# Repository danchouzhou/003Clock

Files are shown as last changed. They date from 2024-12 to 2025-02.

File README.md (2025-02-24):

# 003Clock
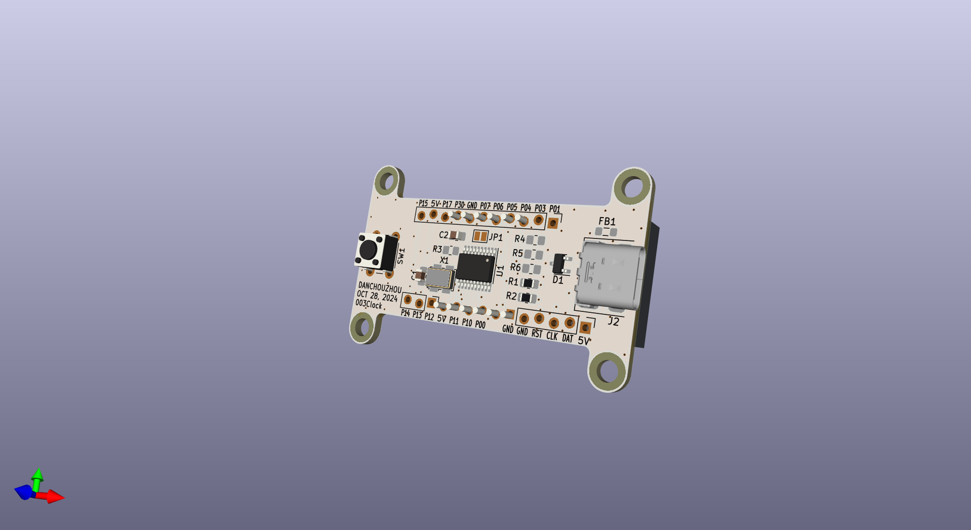
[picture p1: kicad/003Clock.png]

## Usage
### To clone this project
This project work with submodule from Nuvoton corporation. You need to initialize submodules by passing ``--recurse-submodules`` to the ``git clone`` command.
```
git clone https://github.com/danchouzhou/003Clock.git --recurse-submodules
```

### Build tools
Please make sure the installation path is the same as the one in `setting.json`.
- [SDCC 4.2.0](https://sourceforge.net/projects/sdcc/files/sdcc-win64/4.2.0/)
- [Nu-Link_Command_Tool_V3.17.7691r](https://www.nuvoton.com/tool-and-software/software-tool/programmer-tool/)

### Build the firmware
```
cd firmware/003Clock
```
Simply ``./build.bat``. ``main.bin`` should be inside the ``Objects`` folder.
```
./build.bat
```
### Flash the firmware by Nu-Link programmer (ICP)
```
./flash.bat
```
### Flash the firmware without a Nu-Link programmer (ISP)
1. Download the [NuMicro ISP Programming Tool](https://www.nuvoton.com/tool-and-software/software-tool/programmer-tool/)
2. Connect USB-UART adapter to PC
3. Select the COM port and then press `connect`\
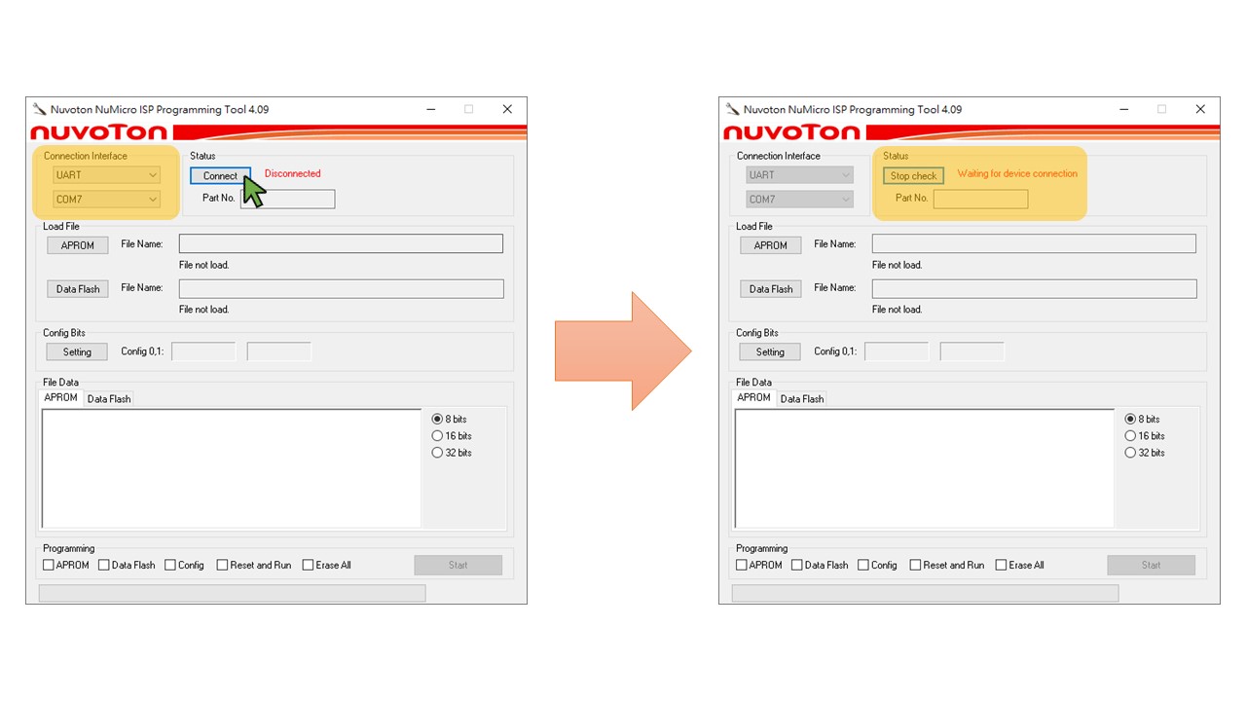
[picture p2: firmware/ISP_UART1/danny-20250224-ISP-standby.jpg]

4. Connect the target device to the USB-UART adapter, ISP Tool should show `connected`\
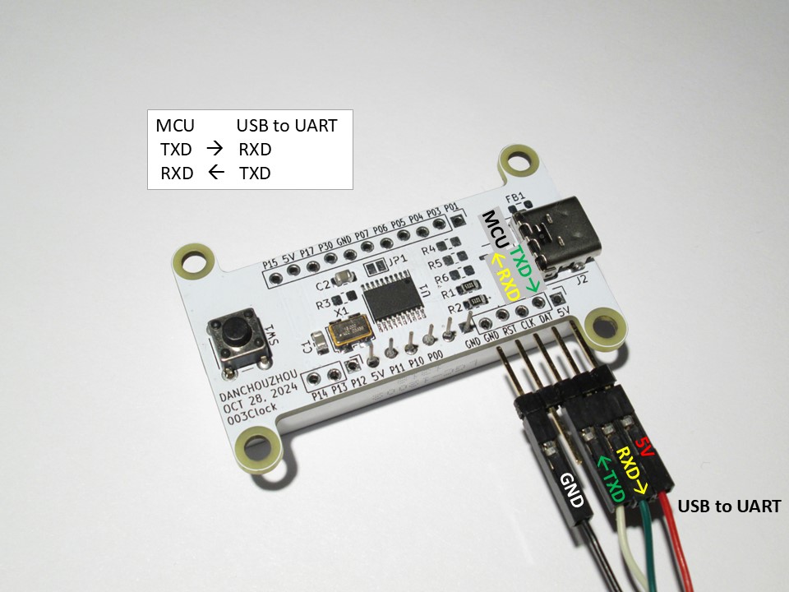
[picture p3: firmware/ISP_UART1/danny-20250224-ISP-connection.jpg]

5. Select APROM file and check `APROM` and `Reset and Run`, then press `Start`\
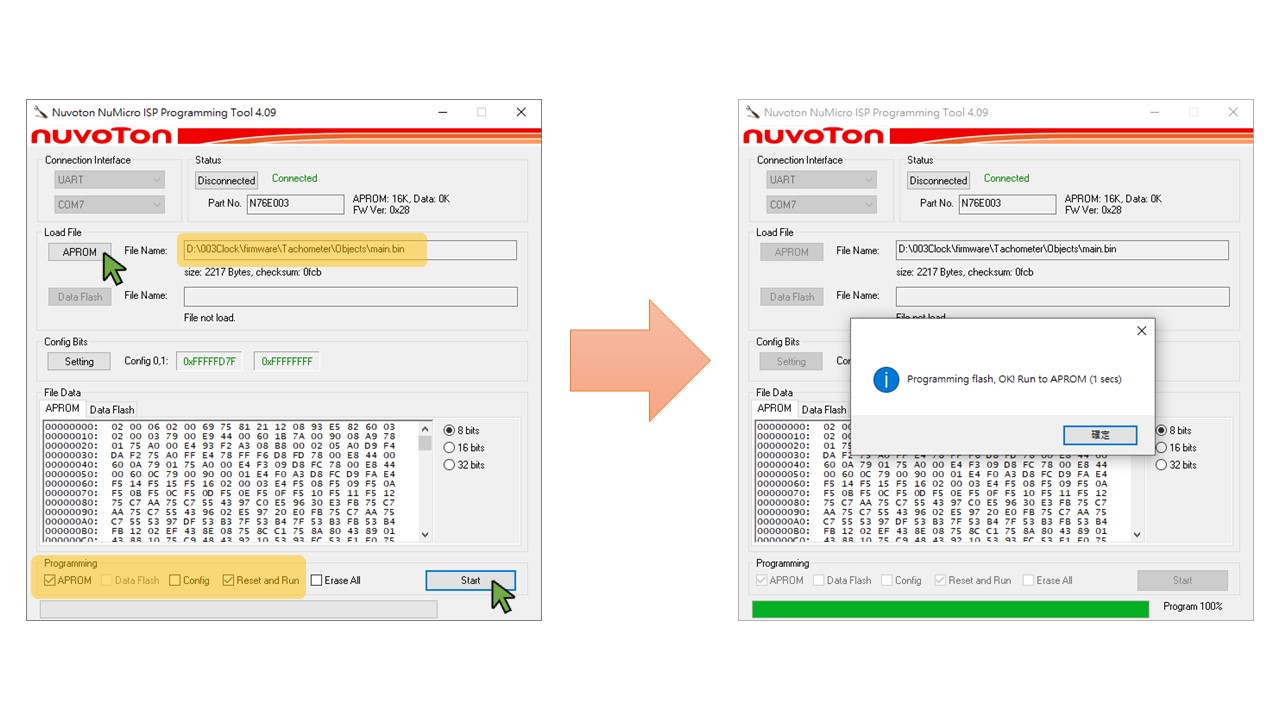
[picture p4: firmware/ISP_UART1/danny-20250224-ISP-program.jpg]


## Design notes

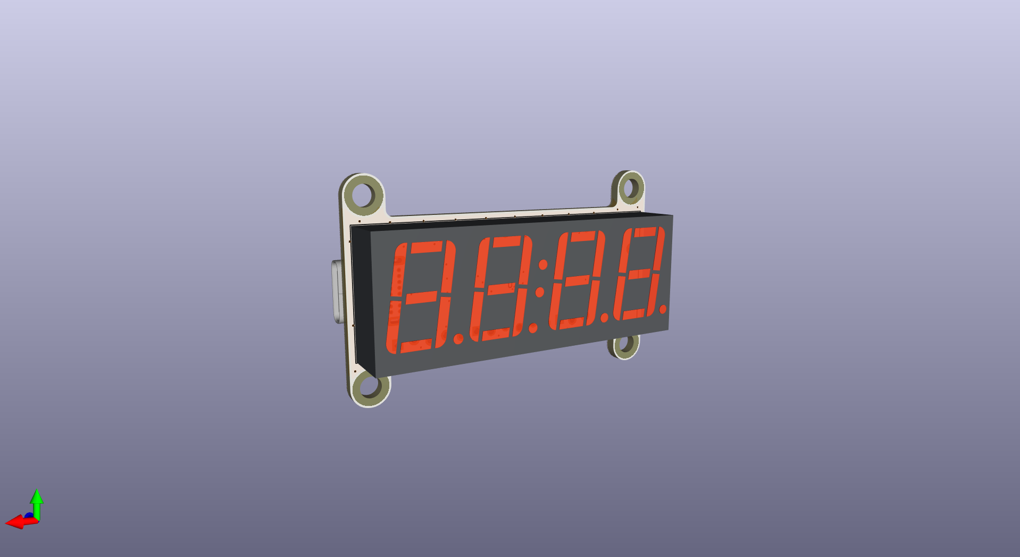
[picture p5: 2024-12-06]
kicad/003Clock_back.png

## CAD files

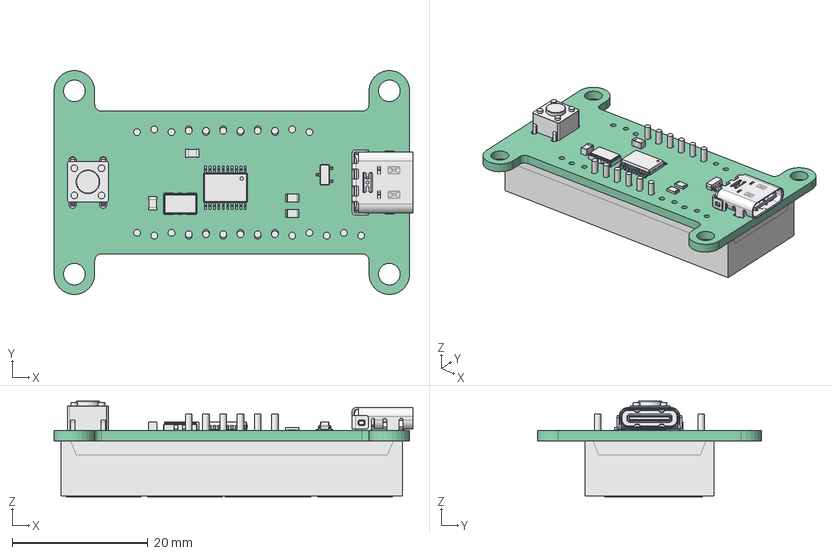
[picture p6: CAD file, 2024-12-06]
freecad/003Clock.FCStd
52.9 x 33.0 x 14.1 mm
Pcb_2389
003Clock.kicad_sch_C_0805_2012Metric_6d379f565624 x 2
Oscillator_SMD_Fox_FT5H_5.0x3.2mm
Oscillator_SMD_Fox_FT5H_5.0x3.2mm001
Oscillator_SMD_Fox_FT5H_5.0x3.2mm002
003Clock.kicad_sch_R_0805_2012Metric_d8bf8b544d5c x 2
003Clock.kicad_sch_TSSOP_20_44x65mm_P065mm_614fd95f1411
003Clock.kicad_sch_SOT_23_332b05a12e7a
003Clock.kicad_sch_SW_PUSH_6mm_a5c7af3cbf73
003Clock.kicad_sch_Fusion004_sp_592efb8ab1cf

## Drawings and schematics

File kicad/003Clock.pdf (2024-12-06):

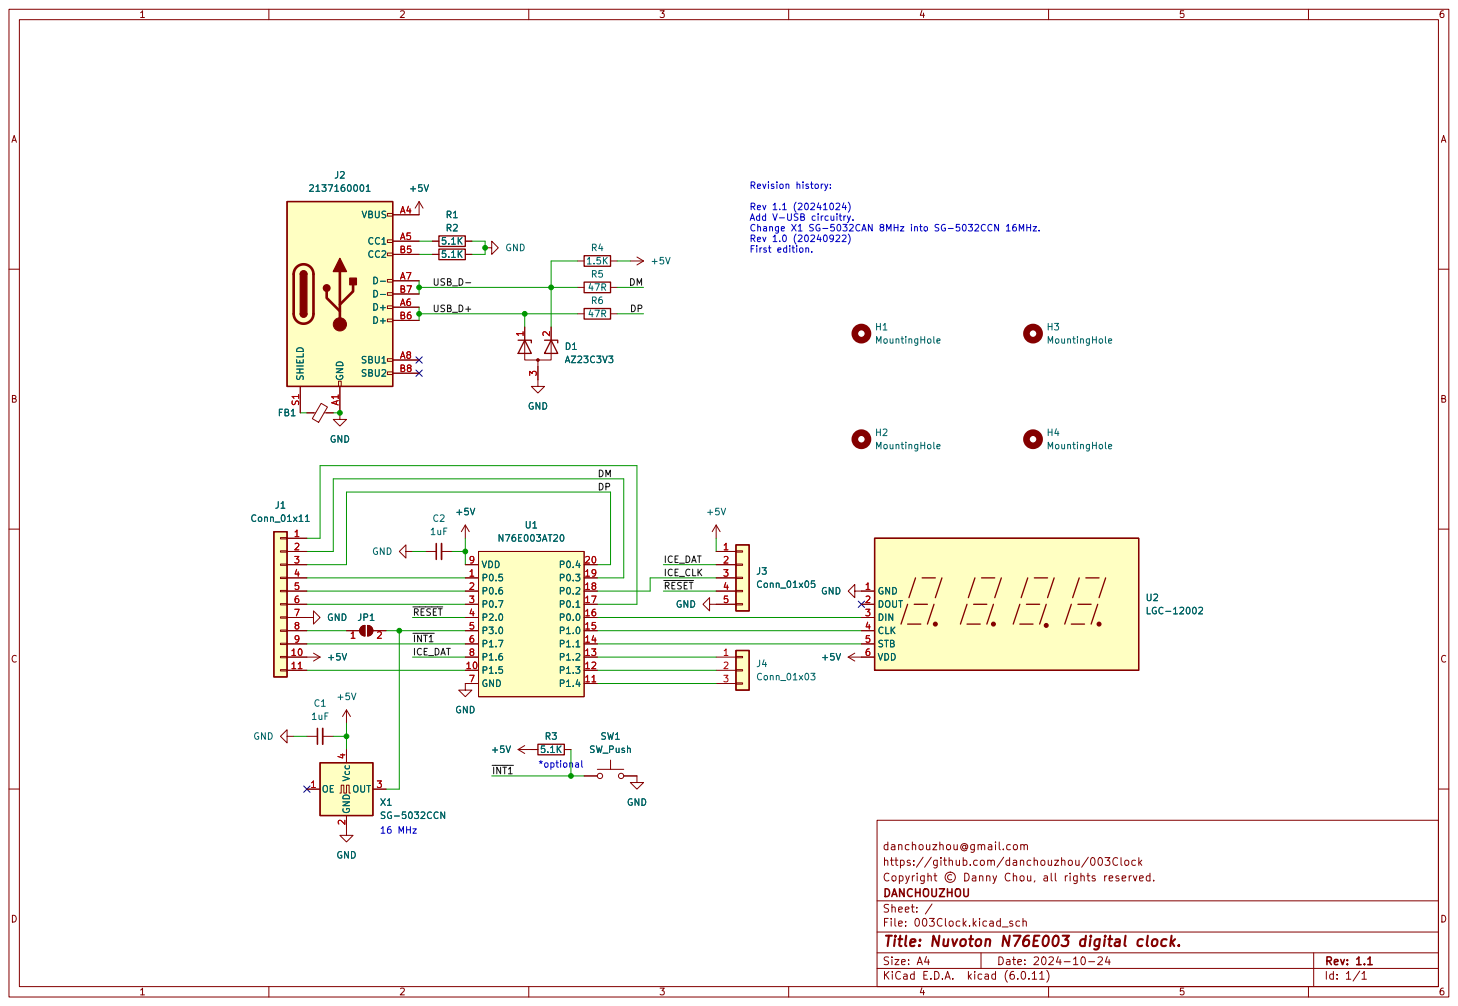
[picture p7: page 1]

Revision history: Rev 1.1 (20241024) Add V-USB circuitry.

Id: 1/1 Title: Nuvoton N76E003 digital clock. File: 003Clock.kicad_sch Sheet: / DANCHOUZHOU

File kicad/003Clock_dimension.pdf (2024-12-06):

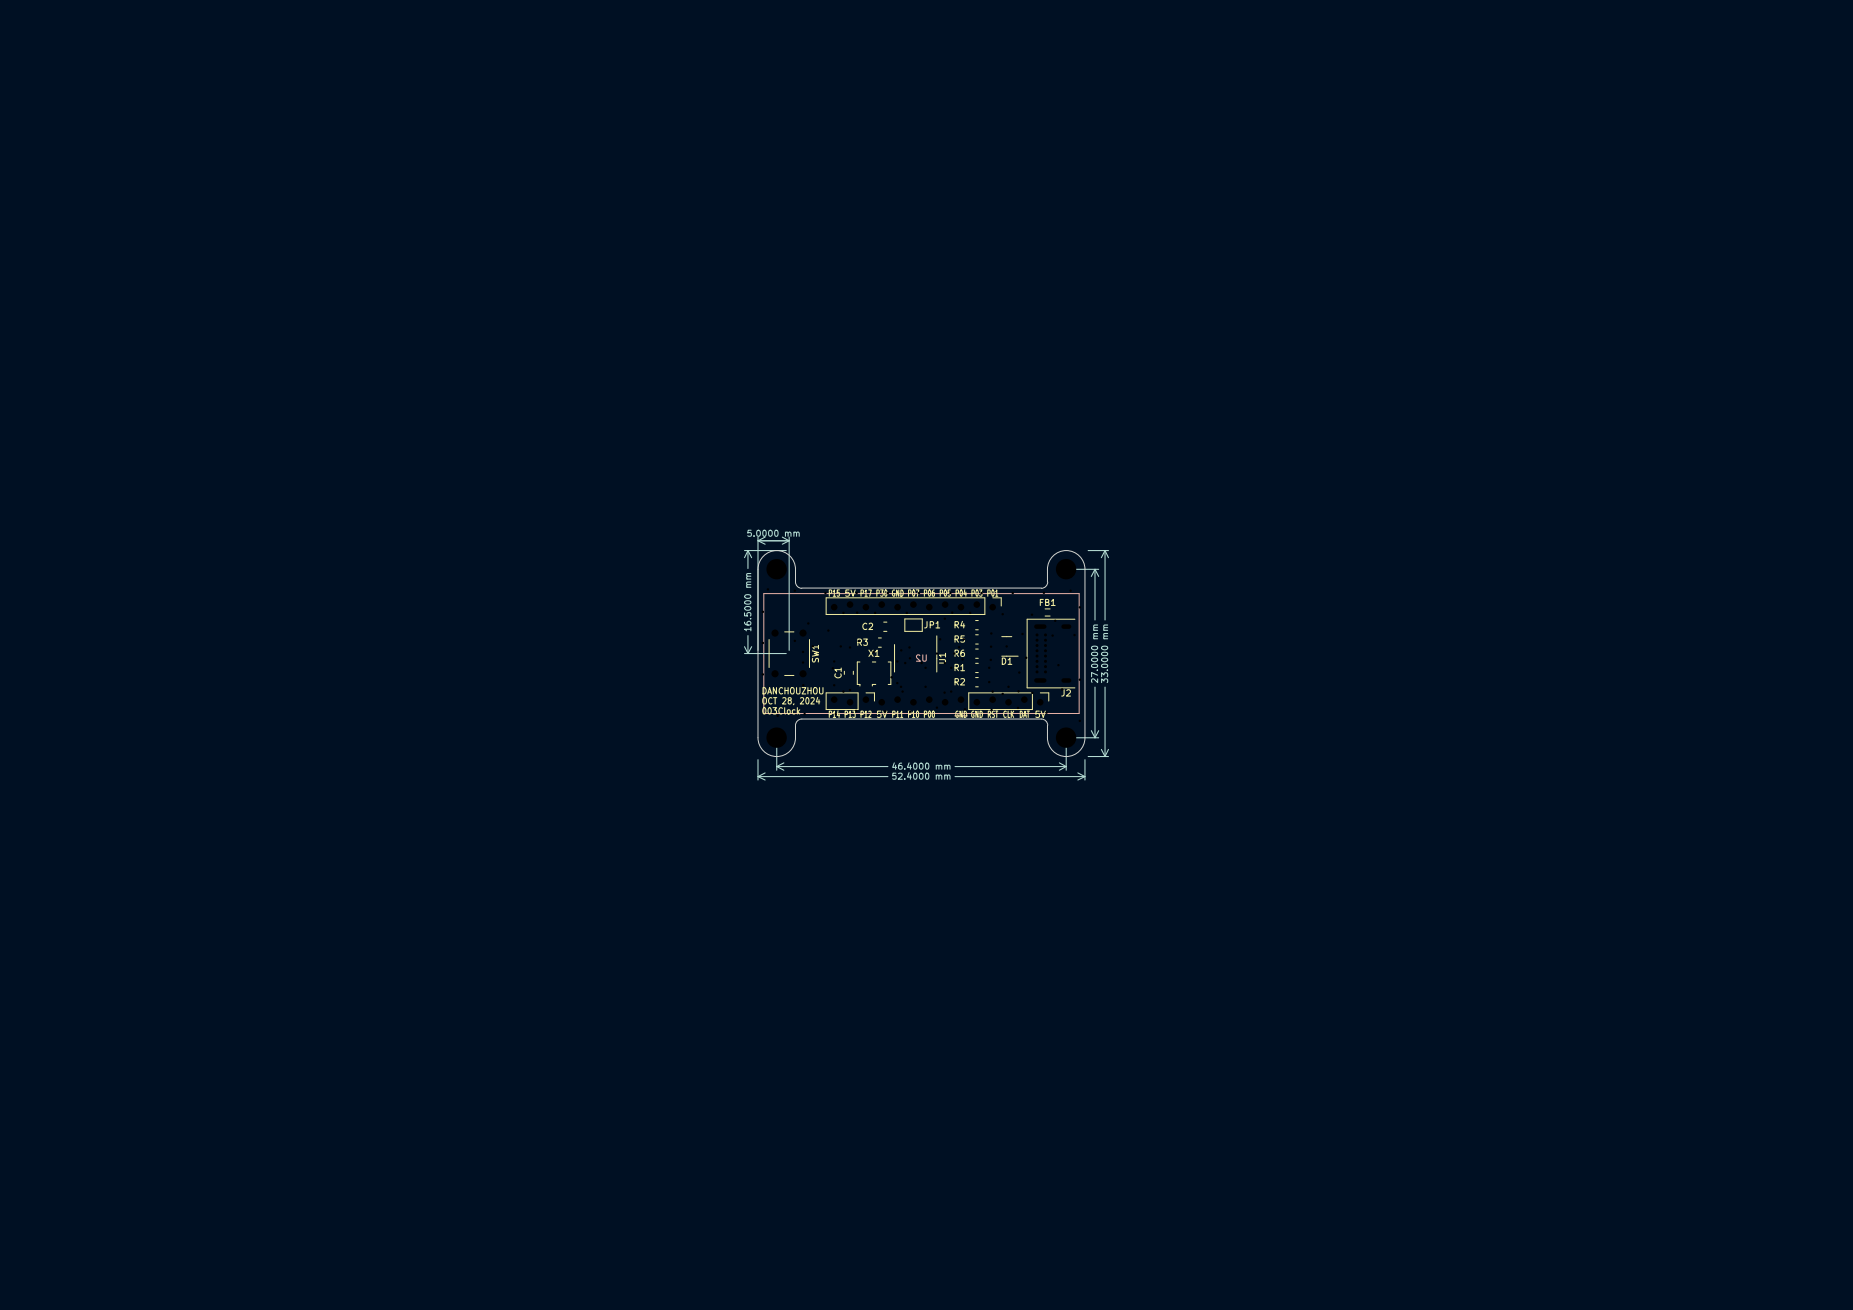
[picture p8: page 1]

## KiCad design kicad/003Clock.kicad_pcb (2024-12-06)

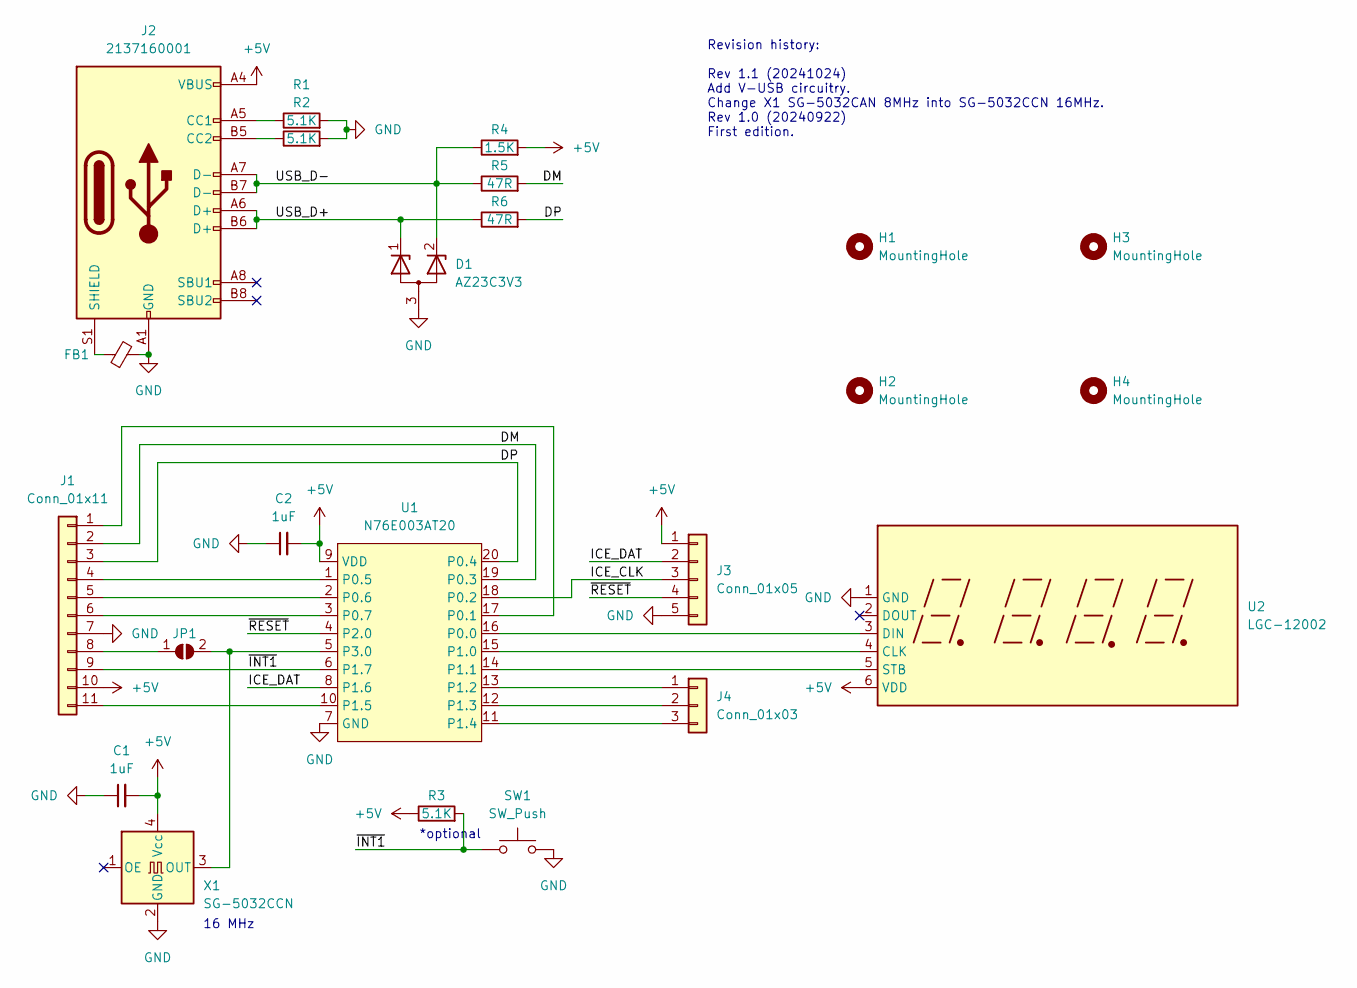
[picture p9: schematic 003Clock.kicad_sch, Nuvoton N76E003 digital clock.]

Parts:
C1, C2: 1uF; C_0805_2012Metric_Pad1.18x1.45mm_HandSolder
D1: AZ23C3V3; SOT-23-3
FB1: FerriteBead_Small; L_0805_2012Metric_Pad1.05x1.20mm_HandSolder
H1, H2, H3, H4: MountingHole; MountingHole_3.2mm_M3_ISO14580
J1: Conn_01x11; PinHeader_1x11_P2.54mm_Vertical
J2: 2137160001
J3: Conn_01x05; PinHeader_1x05_P2.54mm_Vertical
J4: Conn_01x03; PinHeader_1x03_P2.54mm_Vertical
JP1: SolderJumper_2_Open; SolderJumper-2_P1.3mm_Open_Pad1.0x1.5mm
R1, R2, R3: 5.1K; R_0805_2012Metric_Pad1.20x1.40mm_HandSolder
R4: 1.5K; R_0805_2012Metric_Pad1.20x1.40mm_HandSolder
R5, R6: 47R; R_0805_2012Metric_Pad1.20x1.40mm_HandSolder
SW1: SW_Push; SW_PUSH_6mm
U1: N76E003AT20; TSSOP-20_4.4x6.5mm_P0.65mm
U2: LGC-12002
X1: SG-5032CCN; Oscillator_SMD_SeikoEpson_SG8002LB-4Pin_5.0x3.2mm

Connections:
+5V: C1.2, C2.2, J1.10, J2.A4 (VBUS), J2.A9 (VBUS), J2.B4 (VBUS), J2.B9 (VBUS), J3.1, R3.1, R4.2, U1.9 (VDD), U2.6 (VDD), X1.4 (Vcc)
/DM: J1.2, R5.2, U1.19 (P0.3)
/DP: J1.3, R6.2, U1.20 (P0.4)
/ICE_CLK: J3.3, U1.18 (P0.2)
/ICE_DAT: J3.2, U1.8 (P1.6)
/USB_D+: D1.1 (K), J2.A6 (D+), J2.B6 (D+), R6.1
/USB_D-: D1.2 (K), J2.A7 (D-), J2.B7 (D-), R4.1, R5.1
/~INT1: J1.9, R3.2, SW1.1, U1.6 (P1.7)
/~RESET: J3.4, U1.4 (P2.0)
GND: C1.1, C2.1, D1.3 (A), FB1.2, J1.7, J2.A1 (GND), J2.A12 (GND), J2.B1 (GND), J2.B12 (GND), J3.5, R1.2, R2.2, SW1.2, U1.7 (GND), U2.1 (GND), X1.2 (GND)
unnamed: FB1.1, J2.S1 (SHIELD)
unnamed: J1.1, U1.17 (P0.1)
unnamed: J1.4, U1.1 (P0.5)
unnamed: J1.5, U1.2 (P0.6)
unnamed: J1.6, U1.3 (P0.7)
unnamed: J1.8, JP1.1 (A)
unnamed: J1.11, U1.10 (P1.5)
unnamed: J2.A5 (CC1), R1.1
unnamed: J2.B5 (CC2), R2.1
unnamed: J4.1, U1.13 (P1.2)
unnamed: J4.2, U1.12 (P1.3)
unnamed: J4.3, U1.11 (P1.4)
unnamed: JP1.2 (B), U1.5 (P3.0), X1.3 (OUT)
unnamed: U1.14 (P1.1), U2.5 (STB)
unnamed: U1.15 (P1.0), U2.4 (CLK)
unnamed: U1.16 (P0.0), U2.3 (DIN)

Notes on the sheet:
16 MHz
*optional
Revision history: Rev 1.1 (20241024) Add V-USB circuitry. Change X1 SG-5032CAN 8MHz into SG-5032CCN 16MHz. Rev 1.0 (20240922) First edition.

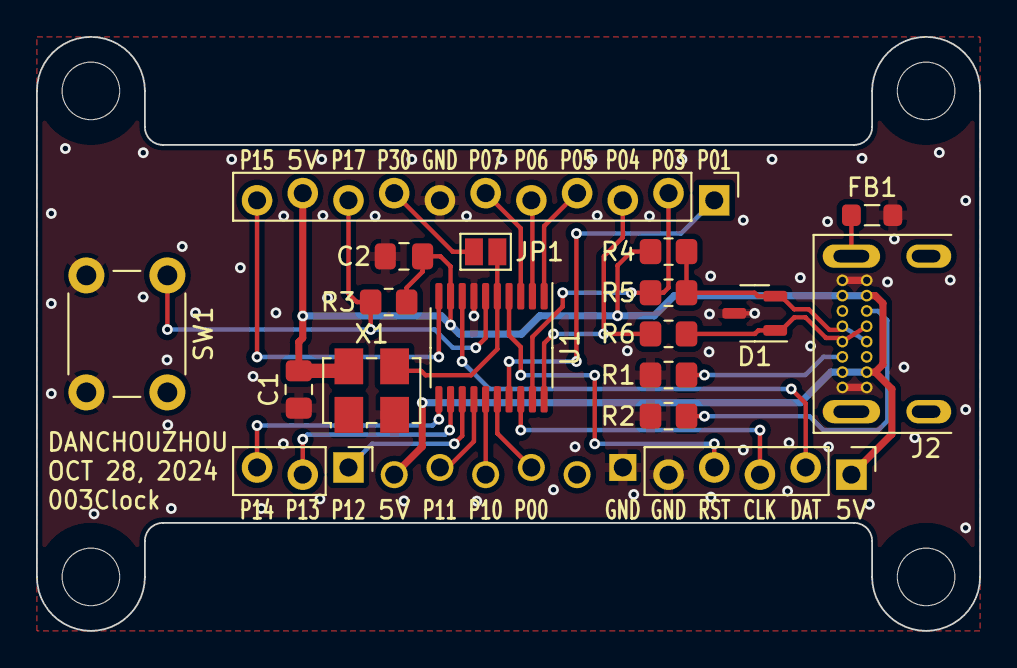
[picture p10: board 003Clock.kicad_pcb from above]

Board: 2 copper layers, 52.4 x 33.0 mm, 23 parts (1 on the bottom side), 26 nets.

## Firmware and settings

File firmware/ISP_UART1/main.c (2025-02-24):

/*---------------------------------------------------------------------------------------------------------*/
/*                                                                                                         */
/* SPDX-License-Identifier: Apache-2.0                                                                     */
/* Copyright(c) 2023 Nuvoton Technology Corp. All rights reserved.                                         */
/*                                                                                                         */
/*---------------------------------------------------------------------------------------------------------*/
#include "numicro_8051.h"
#include "isp_uart1.h"

/******************************
 * @brief     Timer0 interrupt.
 * @param[in] None.
 * @return    None.
 ******************************/
void Timer0_ISR(void) __interrupt(1)
{
    if (g_timer0Counter)
    {
        g_timer0Counter--;
        if (!g_timer0Counter)
            g_timer0Over = 1;
    }

    if (g_timer1Counter)
    {
        g_timer1Counter--;
        if (!g_timer1Counter)
            g_timer1Over = 1;
    }
}

/******************************
 * @brief     Main loop.
 * @param[in] None.
 * @return    None.
 ******************************/
void main(void)
{
    uint8_t vo8temp;
    uint16_t vo16temp;

    set_CHPCON_IAPEN;
    MODIFY_HIRC(HIRC_166);
    /* Initialize UART1 115200 bps for NuMicro ISP Programming Tool */
    UART1_ini_115200_166MHz();
    TM0_ini();

    g_timer0Over = 0;
    g_timer0Counter = 100;
    g_progarmflag = 0;

    while (1)
    {
        /* UART1 handler */
        if (RI_1 == 1)
        {
            vo8temp = SBUF_1;
            uart_rcvbuf[bufhead++] = vo8temp;
            RI_1 = 0; // Clear RI (Receive Interrupt).
        }
        if (TI_1 == 1)
        {
            TI_1 = 0; // Clear TI (Transmit Interrupt).
        }
        if (bufhead == 1)
        {
            g_timer1Over = 0;
            g_timer1Counter = 90; // Reload UART1 timeout interval
        }
        if (bufhead == 64)
        {
            bUartDataReady = TRUE;
            g_timer1Counter = 0;
            g_timer1Over = 0;
            bufhead = 0;
        }

        /* ISP handler */
        if (bUartDataReady == TRUE)
        {
            EA = 0; // Disable all interrupt
            if (g_progarmflag == 1)
            {
                for (count = 8; count < 64; count++)
                {
                    IAPCN = BYTE_PROGRAM_AP; // Byte programming
                    IAPAL = flash_address & 0xff;
                    IAPAH = (flash_address >> 8) & 0xff;
                    IAPFD = uart_rcvbuf[count];
                    trig_IAPGO;

                    IAPCN = BYTE_READ_AP; // Byte read
                    trig_IAPGO;
                    vo8temp = uart_rcvbuf[count];
                    if (IAPFD != vo8temp)
                        while (1);
                    if (CHPCON == 0x43) // Held ISP progress if there is an error
                        while (1);

                    g_totalchecksum += vo8temp;
                    flash_address++;
                    vo16temp = AP_size;
                    if (flash_address == vo16temp)
                    {
                        g_progarmflag = 0;
                        g_timer0Over = 1;
                        goto END_2;
                    }
                }
            END_2:
                Package_checksum();
                uart_txbuf[8] = g_totalchecksum & 0xff;
                uart_txbuf[9] = (g_totalchecksum >> 8) & 0xff;
                Send_64byte_To_UART1();
            }

            switch (uart_rcvbuf[0])
            {
                case CMD_CONNECT:
                case CMD_SYNC_PACKNO:
                    Package_checksum();
                    Send_64byte_To_UART1();
                    g_timer0Counter = 0; // Stop timeout counter
                    g_timer0Over = 0;
                    break;

                case CMD_GET_FWVER:
                    Package_checksum();
                    uart_txbuf[8] = FW_VERSION;
                    Send_64byte_To_UART1();
                    break;

                case CMD_RUN_APROM:
                    goto _APROM;
                    break;

                // Request from NuMicro ISP Programming Tool, get device ID by using following rule
                case CMD_GET_DEVICEID:
                    READ_ID();
                    Package_checksum();
                    uart_txbuf[8] = DID_lowB;
                    uart_txbuf[9] = DID_highB;
                    uart_txbuf[10] = 0;
                    uart_txbuf[11] = 0;
                    Send_64byte_To_UART1();
                    break;

                case CMD_ERASE_ALL:
                    set_IAPUEN_APUEN;
                    IAPFD = 0xFF; // Flash data must be 0xFF for erase command
                    IAPCN = PAGE_ERASE_AP;

                    for (flash_address = 0x0000; flash_address < APROM_SIZE / PAGE_SIZE; flash_address++)
                    {
                        IAPAL = LOBYTE(flash_address * PAGE_SIZE);
                        IAPAH = HIBYTE(flash_address * PAGE_SIZE);
                        trig_IAPGO;
                    }
                    Package_checksum();
                    Send_64byte_To_UART1();
                    break;

                case CMD_READ_CONFIG:
                    READ_CONFIG();
                    Package_checksum();
                    uart_txbuf[8] = CONF0;
                    uart_txbuf[9] = CONF1;
                    uart_txbuf[10] = CONF2;
                    uart_txbuf[11] = 0xff;
                    uart_txbuf[12] = CONF4;
                    uart_txbuf[13] = 0xff;
                    uart_txbuf[14] = 0xff;
                    uart_txbuf[15] = 0xff;
                    Send_64byte_To_UART1();
                    break;

                case CMD_UPDATE_CONFIG:
                    recv_CONF0 = uart_rcvbuf[8];
                    recv_CONF1 = uart_rcvbuf[9];
                    recv_CONF2 = uart_rcvbuf[10];
                    recv_CONF4 = uart_rcvbuf[12];
                    /* Erase CONFIG */
                    // set_CHPCON_IAPEN;
                    set_IAPUEN_CFUEN;
                    IAPCN = PAGE_ERASE_CONFIG;
                    IAPAL = 0x00;
                    IAPAH = 0x00;
                    IAPFD = 0xFF;
                    trig_IAPGO;
                    /* Program CONFIG */
                    IAPCN = BYTE_PROGRAM_CONFIG;
                    IAPAL = 0x00;
                    IAPAH = 0x00;
                    IAPFD = recv_CONF0;
                    trig_IAPGO;
                    IAPFD = recv_CONF1;
                    IAPAL = 0x01;
                    trig_IAPGO;
                    IAPAL = 0x02;
                    IAPFD = recv_CONF2;
                    trig_IAPGO;
                    IAPAL = 0x04;
                    IAPFD = recv_CONF4;
                    trig_IAPGO;
                    clr_IAPUEN_CFUEN;
                    /* Read new CONFIG */
                    READ_CONFIG();

                    Package_checksum();
                    uart_txbuf[8] = CONF0;
                    uart_txbuf[9] = CONF1;
                    uart_txbuf[10] = CONF2;
                    uart_txbuf[11] = 0xff;
                    uart_txbuf[12] = CONF4;
                    uart_txbuf[13] = 0xff;
                    uart_txbuf[14] = 0xff;
                    uart_txbuf[15] = 0xff;
                    Send_64byte_To_UART1();
                    break;

                case CMD_UPDATE_APROM:
                    // set_CHPCON_IAPEN;
                    set_IAPUEN_APUEN;
                    IAPFD = 0xFF; // Flash data must be 0xFF for erase command
                    IAPCN = PAGE_ERASE_AP;

                    for (flash_address = 0x0000; flash_address < APROM_SIZE / PAGE_SIZE; flash_address++)
                    {
                        IAPAL = LOBYTE(flash_address * PAGE_SIZE);
                        IAPAH = HIBYTE(flash_address * PAGE_SIZE);
                        trig_IAPGO;
                    }

                    g_totalchecksum = 0;
                    flash_address = 0;
                    AP_size = 0;
                    AP_size = uart_rcvbuf[12];
                    vo8temp = uart_rcvbuf[13];
                    AP_size |= (vo8temp << 8);
                    g_progarmflag = 1;

                    for (count = 16; count < 64; count++)
                    {
                        IAPCN = BYTE_PROGRAM_AP;
                        IAPAL = flash_address & 0xff;
                        IAPAH = (flash_address >> 8) & 0xff;
                        IAPFD = uart_rcvbuf[count];
                        clr_CHPCON_IAPFF;
                        trig_IAPGO;

                        IAPCN = BYTE_READ_AP; // Read the programmed data
                        trig_IAPGO;
                        vo8temp = uart_rcvbuf[count];
                        if (IAPFD != vo8temp)
                            while (1)
                                ;
                        if (CHPCON == 0x43) // Held ISP progress if there is an error
                            while (1)
                                ;

                        g_totalchecksum += vo8temp;
                        flash_address++;
                        vo16temp = AP_size;
                        if (flash_address == vo16temp)
                        {
                            g_progarmflag = 0;
                            goto END_1;
                        }
                    }
                END_1:
                    Package_checksum();
                    uart_txbuf[8] = g_totalchecksum & 0xff;
                    uart_txbuf[9] = (g_totalchecksum >> 8) & 0xff;
                    Send_64byte_To_UART1();
                    break;
            }
            bUartDataReady = FALSE;
            bufhead = 0;
            EA = 1;
        }

        // Check connect timer out
        if (g_timer0Over == 1)
            goto _APROM;

        // Check UART1 time out or buffer error
        if (g_timer1Over == 1)
        {
            if ((bufhead < 64) && (bufhead > 0) || (bufhead > 64))
            {
                bufhead = 0;
            }
        }
    }

_APROM:
    MODIFY_HIRC(HIRC_16);
    clr_CHPCON_IAPEN;
    TA = 0xAA;
    TA = 0x55;
    CHPCON = 0x00; // Boot from APROM
    TA = 0xAA;
    TA = 0x55;
    CHPCON = 0x80; // Perform software reset

    /* Trap the CPU */
    while (1);
}

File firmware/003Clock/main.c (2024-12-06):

#include "numicro_8051.h"
#include "PT6961.h"
#include "clock.h"

#define SW1 P17

STR_TIME_T time;
STR_TIME_T stopwatch;
void (*isrFunction)(void);

void Timer3_ISR(void) __interrupt (16)
{
    static uint8_t u8counter;

    if ((u8counter & 0x01) == 0)
    {
        clock(&time, 0);
        clock(&stopwatch, 1);
    }

    u8counter ++;

    (*isrFunction)();

    T3CON &= 0xEF; // Clear TF3
}

void showTime(void)
{
    static uint8_t u8counter;
    static int time_int;

    time_int = getTime(&time);

    if ((u8counter & 0x01) == 0)
    {
        pt6961_setNumberFade(time_int, 0);
    }
    else
    {
        pt6961_setNumberFade(time_int, 1);
    }
    u8counter ++;
}

void showSecond(void)
{
    pt6961_setNumberFade(time.second, 1);
}

void showStopwatch(void)
{
    static uint8_t u8counter;
    static int stopwatch_int;

    stopwatch_int = (int)stopwatch.minute * 100 + stopwatch.second;

    if ((u8counter & 0x01) == 0)
    {
        pt6961_setNumberFade(stopwatch_int, 0);
    }
    else
    {
        pt6961_setNumberFade(stopwatch_int, 1);
    }
    u8counter ++;
}

void showSetup(uint8_t u8blink)
{
    static uint16_t u16counter;
    static int time_int, time_int_last;

    time_int = getTime(&time);

    if (u16counter > 1000 || time_int != time_int_last)
        u16counter = 0;
    else
        u16counter ++;

    if (u16counter < 500)
    {
        pt6961_setNumber(time_int, 1);
    }
    else
    {
        switch (u8blink)
        {
            case 1:
                pt6961_writeCommand(0xC0);
                pt6961_writeByte(0x80); // Light up colon only
                break;
            
            case 2:
                pt6961_writeCommand(0xC2);
                pt6961_writeByte(0x80); // Light up colon only
                break;
            
            case 3:
                pt6961_writeCommand(0xC4);
                pt6961_writeByte(0x00);
                break;
            
            case 4:
                pt6961_writeCommand(0xC6);
                pt6961_writeByte(0x00);
                break;
            
            default:
                break;
        }
    }

    time_int_last = time_int;
}

void main(void) 
{
    uint16_t u16swCount = 0;
    uint8_t u8mode = 0;

    TA = 0xAA;
    TA = 0x55;
    CKEN |= 0xC0; // EXTEN
    while(!(CKSWT & 0x08)); // ECLKST
    TA = 0xAA;
    TA = 0x55;
    CKSWT |= 0x02; // Switch to external clock source
    while(CKEN & 0x01); // CKSWTF
    TA = 0xAA;
    TA = 0x55;
    CKEN &= 0xDF; // Disable HIRC

    P12_PUSHPULL_MODE;
    P17_QUASI_MODE;

    pt6961_init();
    pt6961_setBrightness(4);

    CKCON |= 0x08; // Timer 0 source from Fsys directly
    TH0 = (uint8_t)(49536 >> 8); // 65536 - 16000
    TL0 = (uint8_t)(49536 & 0xFF);
    TMOD |= 0x01; // Timer 0 mode 1
    TCON |= 0x10; // Timer 0 run

    isrFunction = &showTime;

    RH3 = (uint8_t)(3036 >> 8); // 65536 - 62500
    RL3 = (uint8_t)(3036 & 0xFF);
    T3CON = 0x0F; // Timer 3 run, pre-scalar = 1/128
    EIE1 |= 0x02; // Enable timer 3 interrupt
    EA = 1;

    while(1)
    {
        if (!SW1) {
            u16swCount++;
            if (u16swCount == 2000)
                u8mode++;
        }

        switch (u8mode) {
            case 0:
                isrFunction = &showTime;
                if (SW1) {
                    if (u16swCount > 20 && u16swCount < 2000)
                        u8mode = 6;
                    u16swCount = 0;
                }
                break;
            
            case 1:
                EIE1 &= 0xFD; // Disable timer 3 interrupt
                showSetup(u8mode);
                if (SW1) {
                    if (u16swCount > 20 && u16swCount < 2000) {
                        if (time.hour < 14)
                            time.hour += 10;
                        else if (time.hour < 20)
                            time.hour = 20;
                        else
                            time.hour -= 20;
                    }
                    u16swCount = 0;
                }
                break;

            case 2:
                showSetup(u8mode);
                if (SW1) {
                    if (u16swCount > 20 && u16swCount < 2000) {
                        if ((time.hour % 10) < 9 && time.hour < 23)
                            time.hour += 1;
                        else if (time.hour >= 23)
                            time.hour -= 3;
                        else
                            time.hour -= 9;
                    }
                    u16swCount = 0;
                }
                break;

            case 3:
                showSetup(u8mode);
                if (SW1) {
                    if (u16swCount > 20 && u16swCount < 2000) {
                        if (time.minute < 50)
                            time.minute += 10;
                        else
                            time.minute -= 50;
                    }
                    u16swCount = 0;
                }
                break;

            case 4:
                showSetup(u8mode);
                if (SW1) {
                    if (u16swCount > 20 && u16swCount < 2000) {
                        if ((time.minute % 10) < 9)
                            time.minute += 1;
                        else
                            time.minute -= 9;
                    }
                    u16swCount = 0;
                }
                break;

            case 5:
                time.second = 0;
                EIE1 |= 0x02; // Enable timer 3 interrupt
                u8mode = 0;
                break;

            case 6:
                isrFunction = &showSecond;
                if (SW1) {
                    if (u16swCount > 20 && u16swCount < 2000)
                        u8mode = 8;
                    u16swCount = 0;
                }
                break;

            /* case 7: u8mode = 0; break; */

            case 8:
                isrFunction = &showStopwatch;
                if (SW1) {
                    if (u16swCount > 20 && u16swCount < 2000)
                        u8mode = 0;
                    u16swCount = 0;
                }
                break;
            
            case 9:
                stopwatch.minute = 0; // Reset stopwatch then return to mode 8
                stopwatch.second = 0;
                u8mode = 8;
                break;
            
            default:
                u8mode = 0;
        }

        P12 = !P12;

        /* 1 ms delay */
        while (!(TCON & 0x20)); // Wait until timer 0 overflow
        TH0 = (uint8_t)(49536 >> 8); // 65536 - 16000
        TL0 = (uint8_t)(49536 & 0xFF);
        TCON &= 0xDF; // Clear TF0
    }
}

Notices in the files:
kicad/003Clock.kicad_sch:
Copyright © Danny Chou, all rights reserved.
